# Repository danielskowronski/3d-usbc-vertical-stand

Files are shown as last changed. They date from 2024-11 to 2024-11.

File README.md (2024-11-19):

# 3D model - Parametric USB-C vertical stand

Use-cases:

1. [Stand for Qingping CO2 & Temp & RH Monitor](./models/qingping_co2_stand/)

---

## Source parts

### Customizable rounded box

[Customizable rounded box](https://www.thingiverse.com/thing:551484)

by [zapta](https://www.thingiverse.com/zapta) is licensed under the Creative Commons - Public Domain Dedication license.

https://www.printables.com/model/188819-customizable-rounded-box

### usb c cover

[usb c cover](https://www.printables.com/model/853352-usb-c-cover)

by [3DM](https://www.printables.com/@Moarbi_1315672) is licensed under the Creative Commons - Public Domain Dedication license.

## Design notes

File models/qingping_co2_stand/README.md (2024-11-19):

# Stand for Qingping CO2 & Temp & RH Monitor

Allows placement of Qingping CO2 monitor on flat surface with plugged in USB-C cable.

[printables.com/model/1074032-stand-for-qingping-co2-temp-rh-monitor](https://www.printables.com/model/1074032-stand-for-qingping-co2-temp-rh-monitor)

## Description

[Qingping CO2 & Temp & RH Monitor](https://www.qingping.co/co2-temp-rh-monitor/overview) is designed to be hanged on the wall with a provided hook. It's possible to place it on a flat surface out of the box, but then you don't have access to the USB-C port for charging and the screen may get unreadable if the device is below line of sight.

This stand is designed to be used with angled USB-C cables or straight ones with any generic angled adapter. It provides holes for routing cable to the left, right, or back of the stand. Moreover, there are legs added so you can stick adhesive rubber feet to stabilize the device. Designed to be printed upside-down without supports.

Printed with Hyper PLA-CF on Creality K1C at 0.16mm layers, but other materials should be fine as well. The rubber feet used are generic no-name with 10mm diameter and flat bottom (rounded one may cause the device to tip-over on higher angles). Tested USB-C adapters and cables are shown in photos.

Based on https://www.printables.com/model/188819-customizable-rounded-box and https://www.printables.com/model/853352-usb-c-cover

Source code and more context available at [github.com/danielskowronski/3d-usbc-vertical-stand](https://github.com/danielskowronski/3d-usbc-vertical-stand)

## How it's built

- all sizes in millimetres
- [Qingping CO2 & Temp & RH Monitor](https://www.qingping.co/co2-temp-rh-monitor/overview):
  - base is 77x28mm
  - USB-C port is on the bottom:
    - in X-axis (77mm) it's centred
    - in Y-axis (depth) it's skewed towards front: 70% instead of 50%
  - display is best read at an angle
- stand is a reversed base (main body) of a parametric box (bottom of the box is top of the stand)
  - width (X) and depth (Y) are controlled with `base_width` and `base_depth`; values set arbitrarily to approx +10mm size of the device
  - height is controlled with `base_height` and 20mm should be enough for cable; NOTE: this is max height of stand after angled cutting
  - top thickness is controlled with `top_thickness` and must be thin enough to ensure secure connection; 1.5mm seems fine
  - wall thickness is `wall_thickness`; set to be the same as `top_thickness` for ease of use
- legs are cylinders added to edges of base sand body, diameter set via `leg_dia`
- hole for USB-C cable is based on the USB-C cap, not just metal connector; otherwise plastic rim would not fit; offset from front is controlled with `cable_offset_from_front` as a percentage of depth (0.5 would mean centre)
- holes for cables:
  - all have minimal wall above them, i.e. height of the hole is nearly full height of the base; this is to save on material and avoid strain on cable as it's anyway completely flush with the top of the stand
  - side ones are aligned with the top USB-C hole and are wide enough for strain relief of typical cable; controlled with `side_cable_diameter`
  - back one is centred and is wide enough for the entire USB-C plug; this is much wider than the side holes as the depth of the stand is very short, and the adapter doesn't fit entirely inside; controlled with `back_cable_diameter`
- angle in degrees is set as parameter of `qp_stand_angled(angle)`:
  - 0 means no angle = no cutting
  - negative value makes the front of the device higher, suitable for looking at the device from top
  - positive value makes the front of the device lower, suitable for looking at the device from bottom

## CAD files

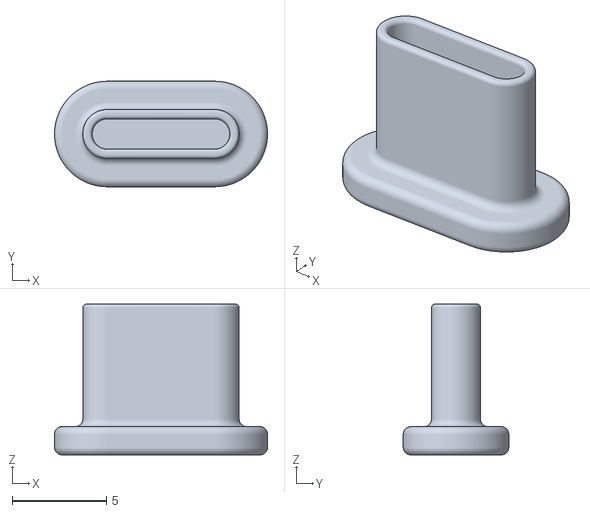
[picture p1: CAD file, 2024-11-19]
usb c cover.stl
11.3 x 5.60 x 8.00

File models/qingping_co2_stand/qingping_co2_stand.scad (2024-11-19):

include <../../rounded_box.scad>

base_width=85;
base_depth=35;
base_height=20;

back_cable_diameter=15;
side_cable_diameter=7.5;

wall_thickness=1.5;
top_thickness=1.5;

leg_dia=10;

cable_offset_from_front=0.4;

module qp_base(){
    rounded_box(
        part_selector=1,
        external_length=base_width,
        external_width=base_depth,
        base_height=base_height,
        wall_thickness=wall_thickness,
        bottom_thickness=top_thickness,
        external_corner_radius=leg_dia/2
    );
}
module qp_cable_hole(){
    translate([-122.25,-125.25,0]) // align source STL to have edges on XYZ axes
    translate([
        base_width/2 - 11.3/2, // X: center on base, center on plug center
        base_depth*cable_offset_from_front - 5.6/2, // Y: 30% from front, center on plug center
        -0
    ])
    import("../../usb c cover.stl"); //11.3 x 5.6 x 8 mm
}
module qp_side_holes(){
    translate([0,base_depth*cable_offset_from_front-side_cable_diameter/2,2*top_thickness])
    cube([base_width,side_cable_diameter,base_height]);
}
module qp_back_hole(){
    translate([base_width/2-back_cable_diameter/2,base_depth-wall_thickness,2*top_thickness])
    cube([back_cable_diameter,wall_thickness,base_height]);
}

module qp_leg(){
    translate([leg_dia/2,leg_dia/2,base_height/2])
    cylinder(base_height, leg_dia/2, leg_dia/2, center=true, $fn=360);
}
module qp_all_legs(){
    qp_leg();
    translate([base_width-leg_dia,0,0]) qp_leg();
    translate([base_width-leg_dia,base_depth-leg_dia,0]) qp_leg();
    translate([0,base_depth-leg_dia,0]) qp_leg();
}

module qp_stand_simple(){
    qp_all_legs();
    difference(){
        qp_base();
        qp_cable_hole();
        qp_side_holes();
        qp_back_hole();
    };
}

module qp_stand_angled(angle){
    difference(){
        qp_stand_simple();
        
        color("red")
        translate([base_width/2,base_depth/2,2*base_height-abs(base_depth*sin(angle))/2]) 
        rotate([(angle),0,0])
        cube(center=true,[1*base_width,2*base_depth,2*base_height]); 
    }
}

qp_stand_angled(-5);

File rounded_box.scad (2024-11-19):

// code in this module is taken straigh from `Customizable rounded box`
// by zapta is licensed under the Creative Commons - Public Domain Dedication license.
// original model page: https://www.thingiverse.com/thing:551484/files

module rounded_box(

// All dimensions are in mm.
// 1 for base only, 2 for cover only, 3 for both.
part_selector = 3,  // [1:Base,2:Cover,3:Both]
// External length of the base and cover.
external_length = 60,
// External width of the base and cover.
external_width = 60,
// Height of the box without the cover.
base_height = 50,
// Thickness of the open box's walls.
wall_thickness = 2.5,
// Thickness of the bottom.
bottom_thickness = 2.5,
// Radius of the external corners.
external_corner_radius = 6,
// The external (visible) height of the cover.
cover_external_height = 3,
// The internal (invisible) height of the cover.
cover_internal_height = 6,
// The real thickness of the cover.
cover_thickness = 2,
// Clearance between the box walls and the cover.
cover_internal_margin = 0.5,
// The thickiness of the internal walls of the cover.
cover_wall_thickness = 2,
// Cover printing offset (when printing both cover and cover)
cover_printing_y_offset = 10

){



                                                                                                                   // Customizeable rounder box with cover.
// See customizer documentation here http://customizer.makerbot.com/docs

// TODO: clean formatting.
// TODO: handle gracefully inconsistnet parameters. Now can result zero material.



/* [Hidden] */

$fn = 180;
eps = 0.001;
eps2 = 2*eps;

base_internal_corner_radius = max(eps, external_corner_radius-wall_thickness);
cover_internal_corner_radius1 = max(eps, base_internal_corner_radius - cover_internal_margin);
cover_internal_corner_radius2 = max(eps, cover_internal_corner_radius1 - cover_wall_thickness);

// Move cover when printing both.
cover_y = (part_selector == 3) ? (external_width + cover_printing_y_offset) : 0;

module rounded_solid_box(xlen, ylen, zlen, r) {
  translate([r, r, 0]) minkowski() {
    cube([xlen-2*r, ylen-2*r, zlen/2]);
    cylinder(r=r, h=zlen/2);
 }
}

module box() {
  difference() {
    rounded_solid_box(external_length, external_width, base_height, external_corner_radius);

    translate([wall_thickness, wall_thickness, bottom_thickness]) 
      rounded_solid_box(
          external_length-2*wall_thickness, 
          external_width-2*wall_thickness, 
          base_height, 
          base_internal_corner_radius);
  }
}

module cover() {
  difference() {
    union() {
      translate([0, cover_y, 0])
      rounded_solid_box(external_length, external_width, cover_external_height, external_corner_radius);
   
      translate([
        wall_thickness + cover_internal_margin,
        cover_y + wall_thickness + cover_internal_margin,
        cover_external_height
      ])
        rounded_solid_box(
          external_length - 2*(wall_thickness + cover_internal_margin) , 
          external_width - 2*(wall_thickness + cover_internal_margin), 
          cover_internal_height + eps, cover_internal_corner_radius1);
    }
      translate([
          wall_thickness + cover_internal_margin + cover_wall_thickness,
          cover_y + wall_thickness + cover_internal_margin + cover_wall_thickness,
        cover_thickness - eps])
        rounded_solid_box(
            external_length - 2*(wall_thickness + cover_internal_margin + cover_wall_thickness), 
            external_width - 2*(wall_thickness + cover_internal_margin+cover_wall_thickness), 
            cover_external_height + cover_internal_height, cover_internal_corner_radius2);

    //translate([6, cover_y + 26, 7]) rotate([0, 180, 0]) scale([1.3, 1.3, 3]) import("/Users/tal/Downloads/_prusa/rina_text.stl", convexity=3);
  }

}

if (part_selector == 1 || part_selector == 3) {
  box();
} 

if (part_selector == 2 || part_selector == 3) {
  cover();
} 

//translate([16, 31, 7]) rotate([0, 180, 0]) scale([1.3, 1.3, 3]) import("/Users/tal/Downloads/_prusa/rina_text.stl", convexity=3);




}
